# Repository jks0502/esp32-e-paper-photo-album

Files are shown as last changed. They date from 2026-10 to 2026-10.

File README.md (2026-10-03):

# 基于ESP32的墨水屏相册

一款离线电子相框：ESP32 将黑白点阵图片保存在板载 Flash，通过 4.2 英寸、400 × 300 的黑白电子纸轮播展示。项目包含 Arduino 固件、图片转换工具、硬件接线说明和可打印外壳设计。

> 仓库仅包含获准公开的点阵参考素材，不收录个人实拍照片。私人照片请只放在本地；示例固件数据需在本地生成。

## 功能

- 断网运行，图片和程序存于 ESP32 Flash，USB 5 V 供电。
- 约每 60 秒自动切换一张；短按 BOOT 可切到下一张。
- 400 × 300、1 bit 黑白图片；图片转换工具支持完整构图留白或中心裁切。
- 提供 4.2 英寸 V2 电子纸驱动、接线说明和 FreeCAD 外壳源文件及打印模型。

## 方案思路

电子纸刷新时才耗电，画面在断电后仍会保留。把相册放在 ESP32 内部 Flash，可以省去 SD 卡、Wi-Fi、蓝牙和 RTC 模块。完整刷新通常会出现黑白闪烁，因此本方案以照片展示为主，采用分钟级轮播，并在每次刷新后让屏幕休眠。

## 硬件目标

- Waveshare e-Paper ESP32 Driver Board（板载 ESP32）
- 4.2 英寸黑白 e-Paper V2，400 × 300
- USB 5 V 电源

驱动板和屏幕具体版本会影响驱动选择。当前 `FrameConfig.h` 默认 `FRAME_PANEL_VERSION 2`；请先核对屏幕背标，再使用对应驱动。硬件装配说明见 [`docs/hardware-and-assembly.md`](docs/hardware-and-assembly.md)。

## 编译和烧录

1. 安装 Arduino IDE 2 和 Espressif ESP32 Arduino Core。
2. 打开 `firmware/CoupleFrame/CoupleFrame.ino`，选择 `ESP32 Dev Module`。
3. 设置 Flash Size 为 4 MB，Partition Scheme 为 `Huge APP (3MB No OTA/1MB SPIFFS)`，选中板子的串口。
4. 先生成本地相册数据，再编译：

   ```powershell
   python -m pip install Pillow
   python tools/prepare_photos.py assets/dot-matrix `
     --sketch firmware/CoupleFrame `
     --preview local-preview
   ```

   `Photos.cpp`、`Photos.h` 和 `local-preview/` 是本机生成文件，已列入 `.gitignore`。本地照片放进 `photos/` 后，可把命令中的 `assets/dot-matrix` 改为 `photos`；这些本地照片目录也会被 Git 忽略。

5. 在 Arduino IDE 编译并上传。串口监视器设为 115200 baud。

固件源码不包含 Wi-Fi 密码、云服务密钥或其它联网配置。

## 替换图片

图片转换脚本接受 JPG、JPEG、PNG、BMP 和 WebP；HEIC 请先在本地导出为 JPEG。图片先转换为灰度，再以 Floyd–Steinberg 抖动编码为 400 × 300 的黑白画面。原始输入文件不会被脚本修改。转换结果和固件数组留在本地生成目录；不要把自己的照片或生成文件提交到公开仓库。

仓库提供五张低分辨率点阵参考画，位于 [`assets/dot-matrix/`](assets/dot-matrix/)。

## 外壳

FreeCAD 源文件、生成脚本以及 STL、STEP、OBJ 打印模型位于 [`enclosure/simple-frame/`](enclosure/simple-frame/)。外壳为 4.2 英寸屏设计，实际打印前请按手头驱动板、转接板和 USB 插头复核空间；目前的 CAD 检查不能代替实物试装。

## 验证范围

软件源码和验证记录来自 ESP32 Arduino 环境下的编译与主机模拟工作。主机模拟覆盖轮播计时、按钮防抖、图像数据发送和 BUSY 超时。发布包已移除原私人相册，必须先生成本机 `Photos.cpp`/`Photos.h` 才能编译。没有把固件二进制作为发布内容；真实屏幕效果、实际接线和外壳试装仍需由使用者检查。

## 许可

项目自行编写的代码按 MIT 许可发布；外壳设计文件和文档按 CC BY 4.0 发布。公开点阵参考图仅包含屏幕尺寸的黑白版本，不含原始实拍图。Waveshare 驱动文件保留原版权及许可声明，第三方许可证见 [`THIRD_PARTY_LICENSE_LGPL-2.1.txt`](THIRD_PARTY_LICENSE_LGPL-2.1.txt)。

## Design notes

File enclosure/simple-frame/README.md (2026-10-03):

# FreeCAD enclosure source and print exports

The enclosure source and exports in this directory are provided under CC BY 4.0. `build_case.py` creates the editable FreeCAD model and printable parts. The STL, STEP, and OBJ files are interchange exports.

The design targets a 4.2-inch, 400×300 panel. Its driver and adapter clearances are design envelopes, not measured guarantees. The recorded CAD checks report `physical_fit_verified: false`; measure your actual hardware and test-fit before printing a full set.

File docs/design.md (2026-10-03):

# 设计说明

## 系统组成

```text
本地图片 → 灰度/抖动转换 → 400×300 单色位图 → ESP32 Flash → SPI → 电子纸
                                          ↑
                                     BOOT 手动换页
```

图片以每像素 1 bit 存储，每帧 15,000 字节。数组放在 Flash；刷新时只把当前帧复制到 RAM。程序从第一张开始，自动轮播到末尾后回到开头；BOOT 低电平按下并做 30 ms 防抖，触发下一张。

## 为什么选择离线相册

- 图片数量有限且固定，适合直接打包进 Flash，结构简单。
- 不依赖家庭网络、账号、服务器或云端照片服务。
- 电子纸断电后保留最后画面，适合 USB 供电的桌面相框。
- 定时完整刷新减少刷新频次；屏幕刷新完成后进入休眠。

## 数据保护

仓库只含五张经允许公开的 400×300 点阵参考图。私人原图、个人照片目录、转换产生的固件数组、预览图、编译产物和固件二进制不随仓库发布。`.gitignore` 也排除了默认照片和本机生成文件。

## 文件导览

- `firmware/CoupleFrame/`：Arduino 主程序、轮播调度、按钮逻辑及 Waveshare 驱动。
- `tools/prepare_photos.py`：本地图片预处理和 C++ 数组生成。
- `assets/dot-matrix/`：屏幕分辨率的点阵演示素材。
- `tests/`：主机侧固件和图像转换检查。
- `enclosure/simple-frame/`：FreeCAD 建模源文件与打印格式导出件。
- `docs/hardware-and-assembly.md`：目标硬件、接线和烧录注意事项。

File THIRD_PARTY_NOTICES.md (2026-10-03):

# Third-party notices

The Waveshare e-Paper driver sources in `firmware/CoupleFrame/src/waveshare/` are based on Waveshare's ESP32 e-Paper Driver Board code. Their original copyright and license notices remain in each source file. The vendor package identifies LGPL 2.1; its license text is included as `THIRD_PARTY_LICENSE_LGPL-2.1.txt`.

Source package and official resources are documented in [`docs/Waveshare-driver-source.md`](docs/Waveshare-driver-source.md). Local changes add a BUSY timeout and fail-stop handling; display initialization and data-transfer routines retain the upstream notices.

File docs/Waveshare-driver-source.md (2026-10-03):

# Waveshare driver source

Official resource page: https://docs.waveshare.net/E-Paper_ESP32_Driver_Board/Resources-And-Documents/

The driver files in `firmware/CoupleFrame/src/waveshare/` were copied from the vendor's `E-Paper_ESP32_Driver_Board_Code` package. Original copyright and license comments are retained in source files. The accompanying LGPL 2.1 license is included at the repository root.

Local changes add a 20-second timeout to both `ReadBusy` loops. `DEV_Config` logs the failure and holds reset low. The original initialization commands, LUT, SPI pin mapping, and image transfer sequence were retained. The board pin mapping is SCK=13, MOSI=14, CS=15, DC=27, RST=26, BUSY=25.

The panel revisions use different BUSY levels and initialization commands. Match the driver to the panel revision documented by the vendor; similar dimensions do not imply compatibility. Software simulation cannot replace a real hardware check.

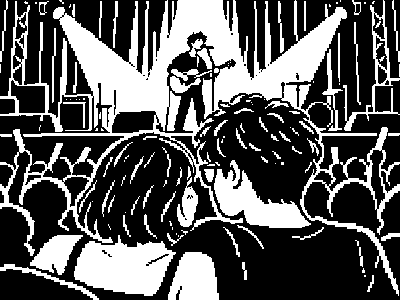
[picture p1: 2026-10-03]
assets/dot-matrix/reference-01.png

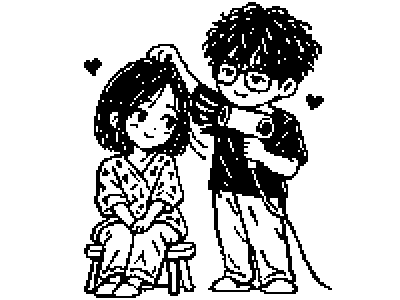
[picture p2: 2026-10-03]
assets/dot-matrix/reference-04.png

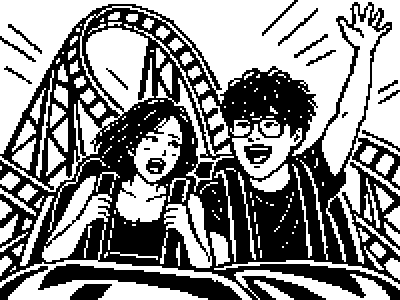
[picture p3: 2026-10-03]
assets/dot-matrix/reference-03.png

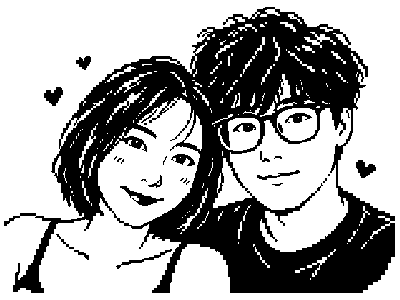
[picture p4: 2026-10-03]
assets/dot-matrix/reference-02.png

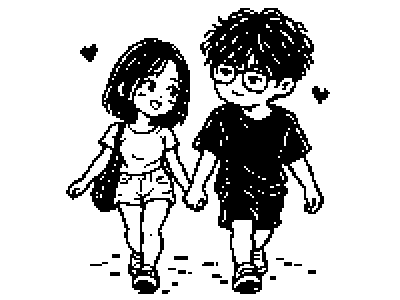
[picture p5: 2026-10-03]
assets/dot-matrix/reference-05.png

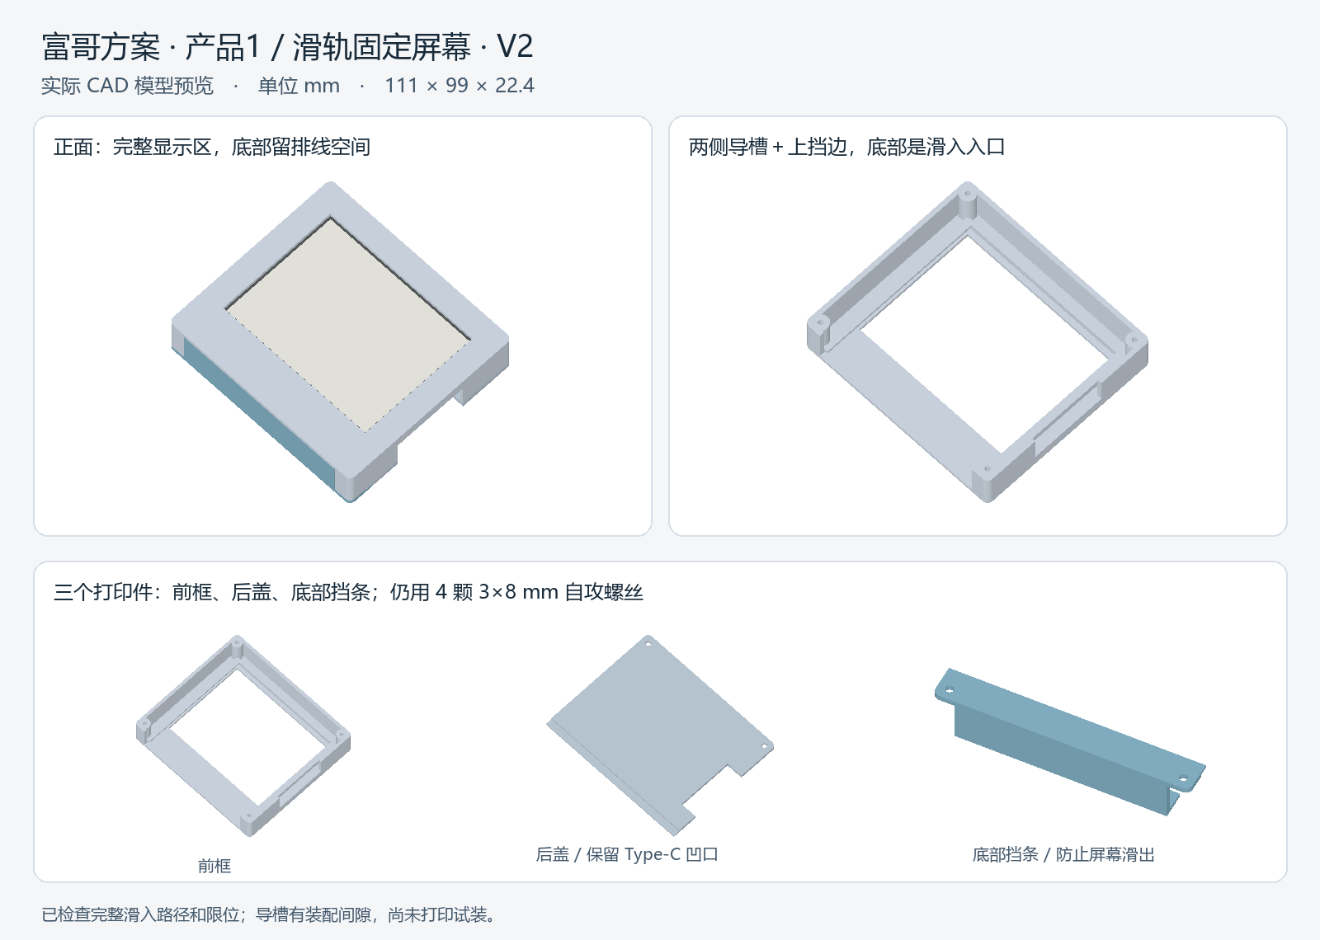
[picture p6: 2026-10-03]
enclosure/simple-frame/case-preview.png

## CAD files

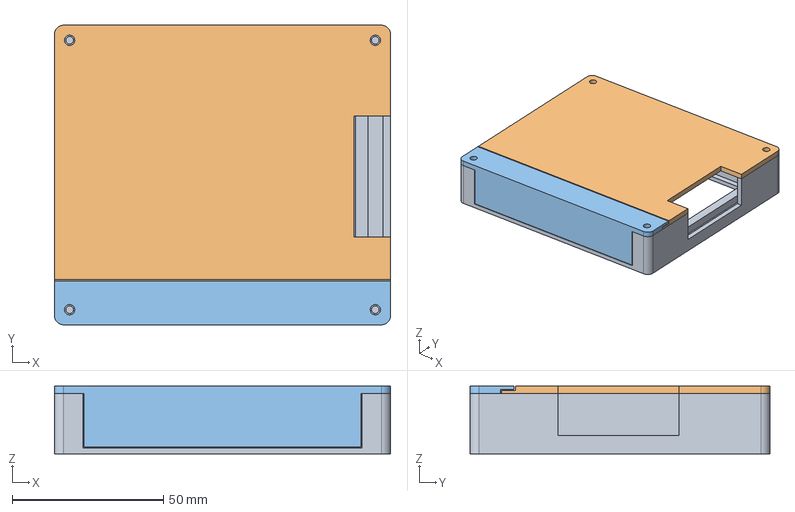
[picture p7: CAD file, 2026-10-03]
enclosure/simple-frame/couple-frame-case.FCStd
111.0 x 99.0 x 22.4 mm
Front frame / slide-in screen rails
Removable back / adhesive board mounting
Bottom entry gate / glass stops

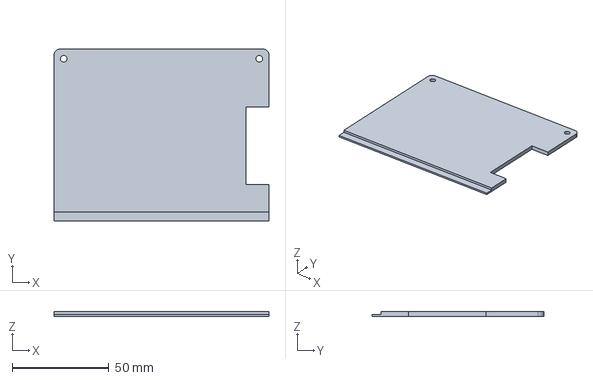
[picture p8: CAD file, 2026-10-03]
enclosure/simple-frame/back.stp
111.0 x 88.7 x 2.40 mm

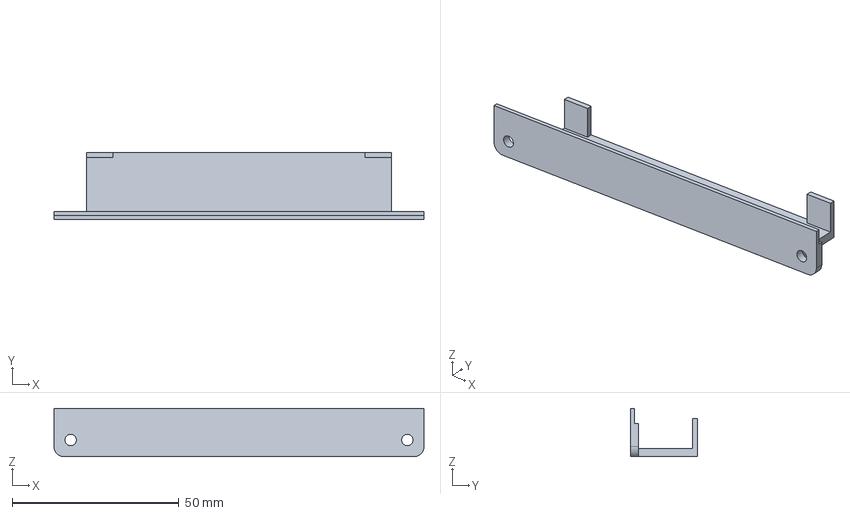
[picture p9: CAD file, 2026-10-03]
enclosure/simple-frame/gate.stp
111.0 x 20.2 x 14.5 mm

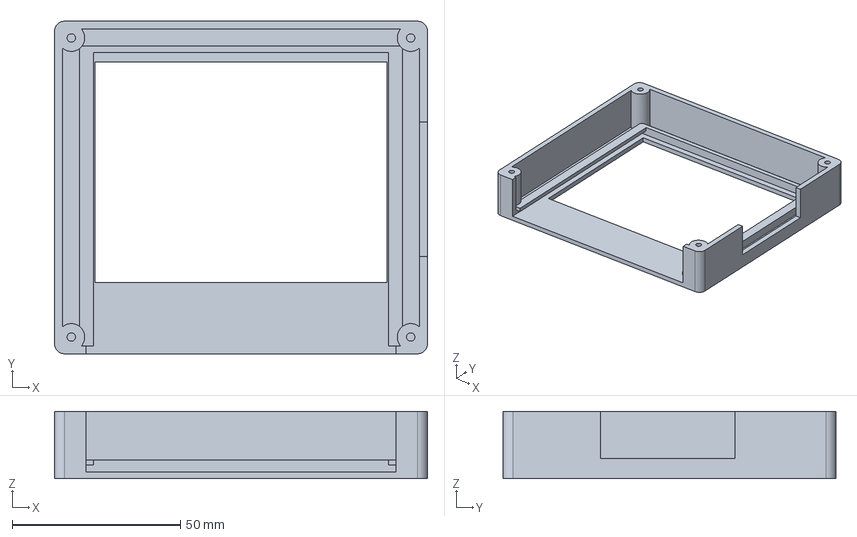
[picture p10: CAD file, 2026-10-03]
enclosure/simple-frame/front.stp
111.0 x 99.0 x 20.0 mm

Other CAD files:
enclosure/simple-frame/back.obj
enclosure/simple-frame/back.stl
enclosure/simple-frame/front.obj
enclosure/simple-frame/front.stl
enclosure/simple-frame/gate.obj
enclosure/simple-frame/gate.stl

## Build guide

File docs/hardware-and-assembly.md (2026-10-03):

# 硬件与装配说明

## 目标硬件

- Waveshare e-Paper ESP32 Driver Board（ESP32-WROOM 系列）
- Waveshare 4.2 英寸黑白裸屏，400×300，V2 驱动
- 板载 Type-C 接口和 USB 5 V 电源

该固件面向 `FRAME_PANEL_VERSION=2`。电子纸外观尺寸相近不代表驱动兼容；请核对屏幕标签和对应厂商手册，不确定时不要直接上电刷新。

## IDE 配置

- Board：`ESP32 Dev Module`
- Flash Size：`4MB (32Mb)`
- Partition Scheme：`Huge APP (3MB No OTA/1MB SPIFFS)`
- Serial Monitor：`115200`

屏幕版本通过 [`firmware/CoupleFrame/FrameConfig.h`](../firmware/CoupleFrame/FrameConfig.h) 中的 `FRAME_PANEL_VERSION` 选择。驱动板型号和屏幕版本是两项独立设置。

## 接线和上电

1. 断开 USB 电源后再插拔屏幕 FPC / FFC 排线。
2. 按驱动板对应版本的厂商手册设置拨码和排线方向；不要仅凭排线颜色猜触点方向。
3. 排线平直插到底并锁紧卡扣，避免弯折、拉扯或压住玻璃。
4. 首次使用保持屏幕平放，上传后观察完整刷新是否结束。
5. 连接器、板卡或屏幕发热、出现异常气味或刷新持续卡住时，立即断电并检查硬件。

## 行为与限制

- 全屏刷新时黑白闪烁是电子纸正常刷新过程。
- 自动计时从一次刷新开始计时，约 60 秒后开始下一次刷新。
- BOOT 手动切图会重置自动计时；刷新期间不缓存按键事件。
- 断电后屏幕通常保留最后画面；程序重新上电后从首张图片开始。
- 本项目没有联网功能，也没有实际外壳打印与试装保证。以你手里的硬件版本和供应商资料为准。

驱动源码来源和局部修改说明见 [`Waveshare-driver-source.md`](Waveshare-driver-source.md)。

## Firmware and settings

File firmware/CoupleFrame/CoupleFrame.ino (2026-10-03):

// 富哥方案 · 产品 1：离线照片相框，每 60 秒开始切换下一张。
// Arduino IDE: ESP32 Dev Module. No external Arduino libraries needed.
#include <Arduino.h>
#include <string.h>
#include "FrameConfig.h"
#include "Slideshow.h"
#include "DebouncedButton.h"
#include "Photos.h"
#include "src/waveshare/DEV_Config.h"
#if FRAME_PANEL_VERSION == 2
#include "src/waveshare/EPD_4in2_V2.h"
#else
#include "src/waveshare/EPD_4in2.h"
#endif

static_assert(kPhotoCount > 0, "At least one photo is required");
static_assert(kPhotoBytes == kFrameBytes, "Photos must be 400 x 300, 1-bit");
static uint8_t frameBuffer[kFrameBytes];
static Slideshow slideshow(kPhotoCount, kPhotoIntervalMs);
static DebouncedButton nextButton(kButtonDebounceMs);

static void showPhoto(size_t index) {
  // ESP32 flash is memory mapped; only the current image needs a RAM buffer.
  memcpy(frameBuffer, kPhotos[index], sizeof(frameBuffer));
  Serial.printf("[frame] t=%lu ms, photo=%u/%u, panel=%d\n",
                (unsigned long)millis(), (unsigned)(index + 1),
                (unsigned)kPhotoCount, FRAME_PANEL_VERSION);
#if FRAME_PANEL_VERSION == 2
  EPD_4IN2_V2_Init();
  EPD_4IN2_V2_Display(frameBuffer);
  EPD_4IN2_V2_Sleep();
#else
  EPD_4IN2_Init_Fast();
  EPD_4IN2_Display(frameBuffer);
  EPD_4IN2_Sleep();
#endif
  Serial.println("[frame] done; screen asleep, next start in the 60-second cycle");
  // Refresh blocks polling. Ignore presses during refresh and held buttons.
  nextButton.begin(digitalRead(kNextButtonPin) == LOW, millis());
}

void setup() {
  DEV_Module_Init();
  pinMode(kNextButtonPin, INPUT_PULLUP);
  Serial.println("CoupleFrame: offline / 400x300 / 60 seconds / BOOT=next");
  // Timing is measured from refresh start to refresh start, not 60 seconds
  // after refreshing. Display work therefore does not accumulate time drift.
  if (!slideshow.begin(millis())) DEV_FailStop("Invalid slideshow settings");
  showPhoto(slideshow.index());
}

void loop() {
  const uint32_t now = millis();
  if (nextButton.pressed(digitalRead(kNextButtonPin) == LOW, now)) {
    if (slideshow.advance(now)) {
      Serial.println("[button] BOOT: next photo; automatic timer restarted");
      showPhoto(slideshow.index());
    }
  } else if (slideshow.advanceIfDue(now)) {
    showPhoto(slideshow.index());
  }
  delay(10); // Yield to the ESP32 scheduler while keeping the minute boundary.
}

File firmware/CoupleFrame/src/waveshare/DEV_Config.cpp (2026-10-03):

/*****************************************************************************
* | File      	:   DEV_Config.c
* | Author      :   Waveshare team
* | Function    :   Hardware underlying interface
* | Info        :
*----------------
* |	This version:   V1.0
* | Date        :   2020-02-19
* | Info        :
#
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
******************************************************************************/
#include "DEV_Config.h"

[[noreturn]] void DEV_FailStop(const char *message)
{
    Serial.print("[ERROR] ");
    Serial.println(message);
    Serial.println("Power off. Check panel version and ribbon connection.");
    // Hold the controller in reset; do not repeatedly retry refresh commands.
    digitalWrite(EPD_RST_PIN, LOW);
    for (;;) delay(1000);
}

void DEV_CheckBusyDeadline(uint32_t started)
{
    if (uint32_t(millis() - started) >= 20000UL)
        DEV_FailStop("Screen BUSY timeout (20 seconds)");
}

void GPIO_Config(void)
{
    pinMode(EPD_BUSY_PIN,  INPUT);
    pinMode(EPD_RST_PIN , OUTPUT);
    pinMode(EPD_DC_PIN  , OUTPUT);
    
    pinMode(EPD_SCK_PIN, OUTPUT);
    pinMode(EPD_MOSI_PIN, OUTPUT);
    pinMode(EPD_CS_PIN , OUTPUT);

    digitalWrite(EPD_CS_PIN , HIGH);
    digitalWrite(EPD_SCK_PIN, LOW);
}

void GPIO_Mode(UWORD GPIO_Pin, UWORD Mode)
{
    if(Mode == 0) {
        pinMode(GPIO_Pin , INPUT);
	} else {
		pinMode(GPIO_Pin , OUTPUT);
	}
}
/******************************************************************************
function:	Module Initialize, the BCM2835 library and initialize the pins, SPI protocol
parameter:
Info:
******************************************************************************/
UBYTE DEV_Module_Init(void)
{
	//gpio
	GPIO_Config();

	//serial printf
	Serial.begin(115200);

	// spi
	// SPI.setDataMode(SPI_MODE0);
	// SPI.setBitOrder(MSBFIRST);
	// SPI.setClockDivider(SPI_CLOCK_DIV4);
	// SPI.begin();

	return 0;
}

/******************************************************************************
function:
			SPI read and write
******************************************************************************/
void DEV_SPI_WriteByte(UBYTE data)
{
    //SPI.beginTransaction(spi_settings);
    digitalWrite(EPD_CS_PIN, GPIO_PIN_RESET);

    for (int i = 0; i < 8; i++)
    {
        if ((data & 0x80) == 0) digitalWrite(EPD_MOSI_PIN, GPIO_PIN_RESET); 
        else                    digitalWrite(EPD_MOSI_PIN, GPIO_PIN_SET);

        data <<= 1;
        digitalWrite(EPD_SCK_PIN, GPIO_PIN_SET);     
        digitalWrite(EPD_SCK_PIN, GPIO_PIN_RESET);
    }

    //SPI.transfer(data);
    digitalWrite(EPD_CS_PIN, GPIO_PIN_SET);
    //SPI.endTransaction();	
}

UBYTE DEV_SPI_ReadByte()
{
    UBYTE j=0xff;
    GPIO_Mode(EPD_MOSI_PIN, 0);
    digitalWrite(EPD_CS_PIN, GPIO_PIN_RESET);
    for (int i = 0; i < 8; i++)
    {
        j = j << 1;
        if (digitalRead(EPD_MOSI_PIN))  j = j | 0x01;
        else                            j = j & 0xfe;
        
        digitalWrite(EPD_SCK_PIN, GPIO_PIN_SET);     
        digitalWrite(EPD_SCK_PIN, GPIO_PIN_RESET);
    }
    digitalWrite(EPD_CS_PIN, GPIO_PIN_SET);
    GPIO_Mode(EPD_MOSI_PIN, 1);
    return j;
}

void DEV_SPI_Write_nByte(UBYTE *pData, UDOUBLE len)
{
    for (int i = 0; i < len; i++)
        DEV_SPI_WriteByte(pData[i]);
}

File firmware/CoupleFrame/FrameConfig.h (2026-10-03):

#pragma once
#include <stdint.h>

// 1 = official epd4in2-demo; 2 = official epd4in2_V2-demo.
// Select using the actual panel label; this is NOT the ESP32 board revision.
// Default target: a Waveshare 4.2-inch e-Paper V2 panel.
#ifndef FRAME_PANEL_VERSION
#define FRAME_PANEL_VERSION 2
#endif
#if FRAME_PANEL_VERSION != 1 && FRAME_PANEL_VERSION != 2
#error "FRAME_PANEL_VERSION must be 1 or 2"
#endif

constexpr uint32_t kPhotoIntervalMs = 60000UL;
constexpr uint8_t kNextButtonPin = 0; // Rev 3 BOOT button, active low.
constexpr uint32_t kButtonDebounceMs = 30UL;
constexpr uint16_t kFrameWidth = 400;
constexpr uint16_t kFrameHeight = 300;
constexpr uint32_t kFrameBytes = kFrameWidth * kFrameHeight / 8;

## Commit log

2026-10-03 feat: publish privacy-safe ESP32 e-paper album source
    [back.obj, back.stl, back.stp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]
2026-10-03 fix: update host test paths for firmware layout
    [test_firmware.cpp]
